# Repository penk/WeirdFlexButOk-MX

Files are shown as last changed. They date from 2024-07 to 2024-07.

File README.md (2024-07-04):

## WeirdFlexButOk - MX version

A hot-swappable, ergo monoblock split keyboard with tenting.

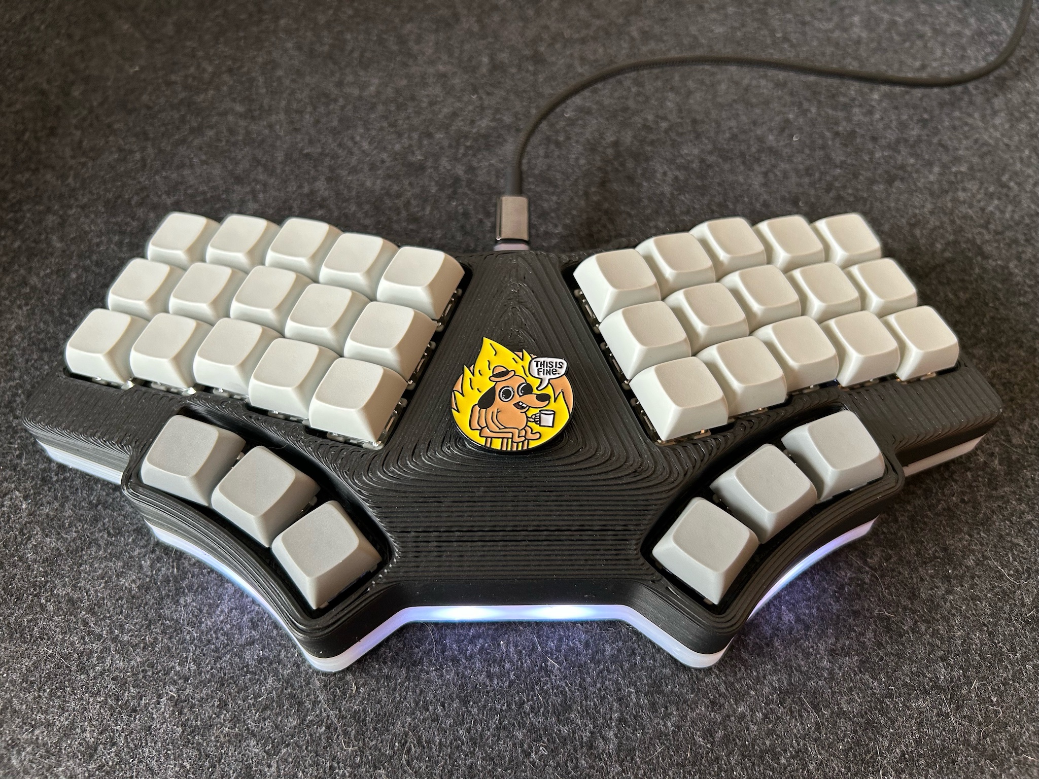
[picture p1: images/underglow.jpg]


Similar to the [Choc version](https://github.com/penk/WeirdFlexButOk), this keyboard features a `0.8mm` PCB with serpentine routing (kerf cuts) near the thumb clusters. These cuts allow the board to flex along the contour of the 3D printed case, forming a `20°` tilt and `10°` tent from a single PCB.

## Features

- Hot-swappable ergo monoblock split in MX spacing
- Built-in tenting (10°) and tilting (20°) from a single FR-4 PCB
- Breakable pinky columns, for 36 or 42-key layouts 
- Optional RGB underglow LEDs

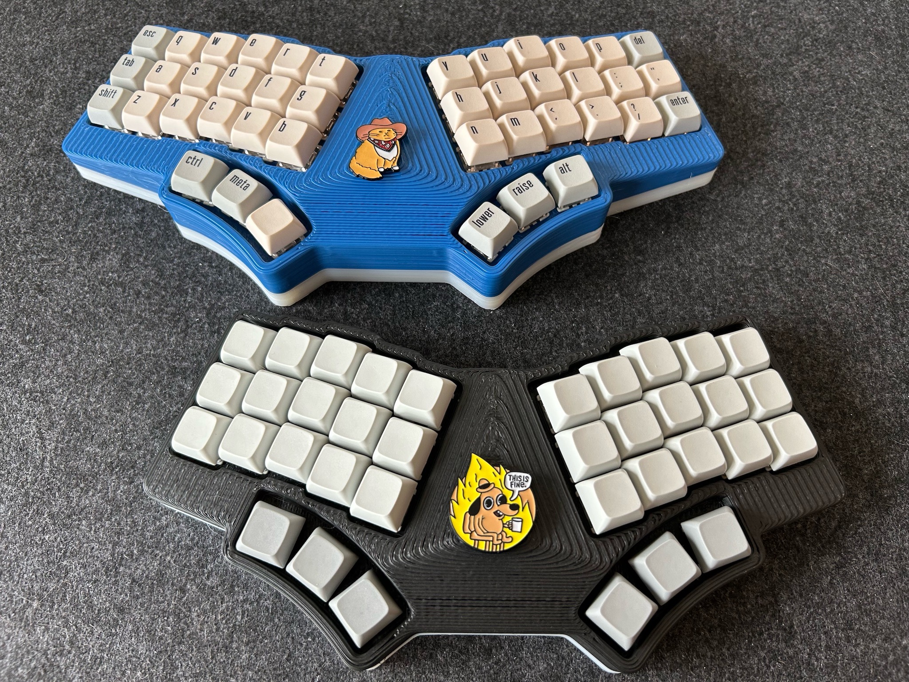
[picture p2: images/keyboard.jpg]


## Bill of Materials (BOM)

Quantity | Item
--- | ---
1 | Enamel pin badge (Optional)
1 | RP2040-Zero 
1 | WeirdFlexButOk-MX PCB
1 | WeirdFlexButOk-MX case & plate
36 (42) | MX Switches
36 (42) | MX Hot-swap sockets
36 (42) | 1N4148SOD-123 diodes
4 | WS2812B LEDs (Optional)
8 | M2x4 heat-set thread inserts
6 | M2x10 standoffs
14 | M2x6 screws

## Production Files

To place an order for the WeirdFlexButOk-MX PCB:

- Use the Gerber files available in the [production/](production/) folder.
- Optionally, the [BOM](production/BOM.csv) and [CPL](production/CPL.csv) files can be utilized with a PCBA service. All components, including the RP2040-Zero, are soldered to the bottom side of the board.

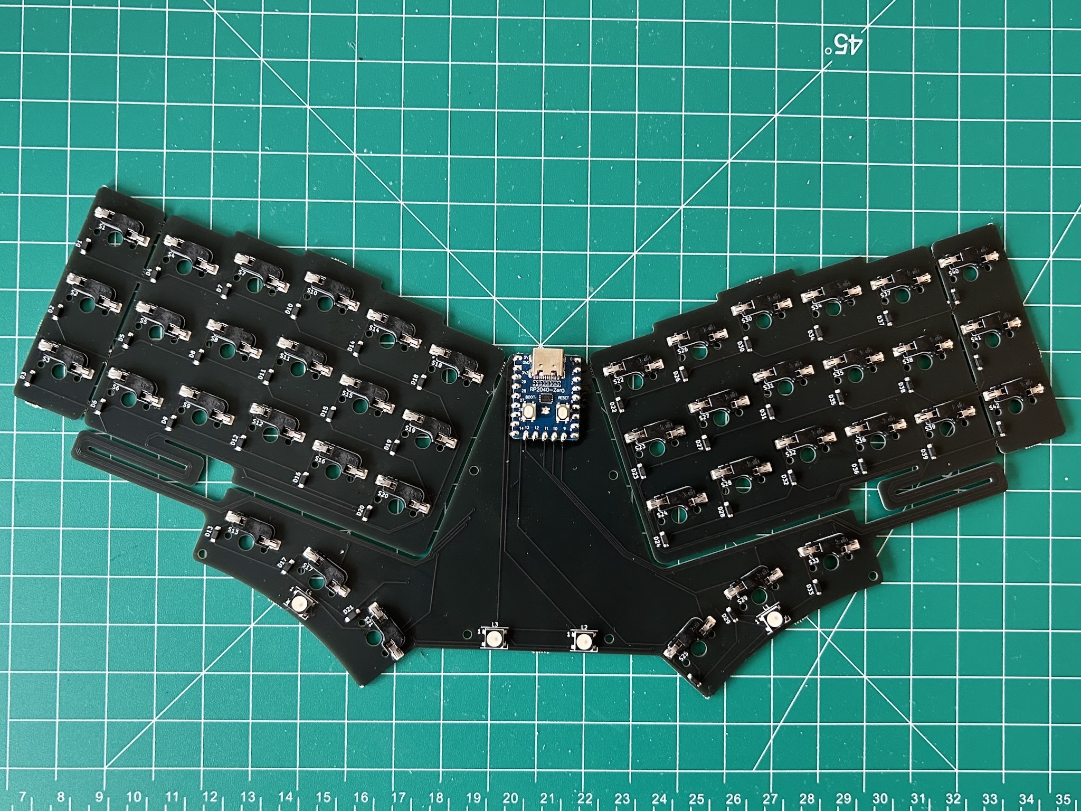
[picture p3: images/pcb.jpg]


Ensure you select the following specifications so the PCB can flex:

- Base Material: `FR4`
- PCB Thickness: `0.8mm`

The complete PCB design project is available in the [kicad/](kicad/) folder.

## 3D Printable Files

Print the case using the provided [STL files](case/) for the 36-key (3x5) or 42-key (3x6) layout respectively.

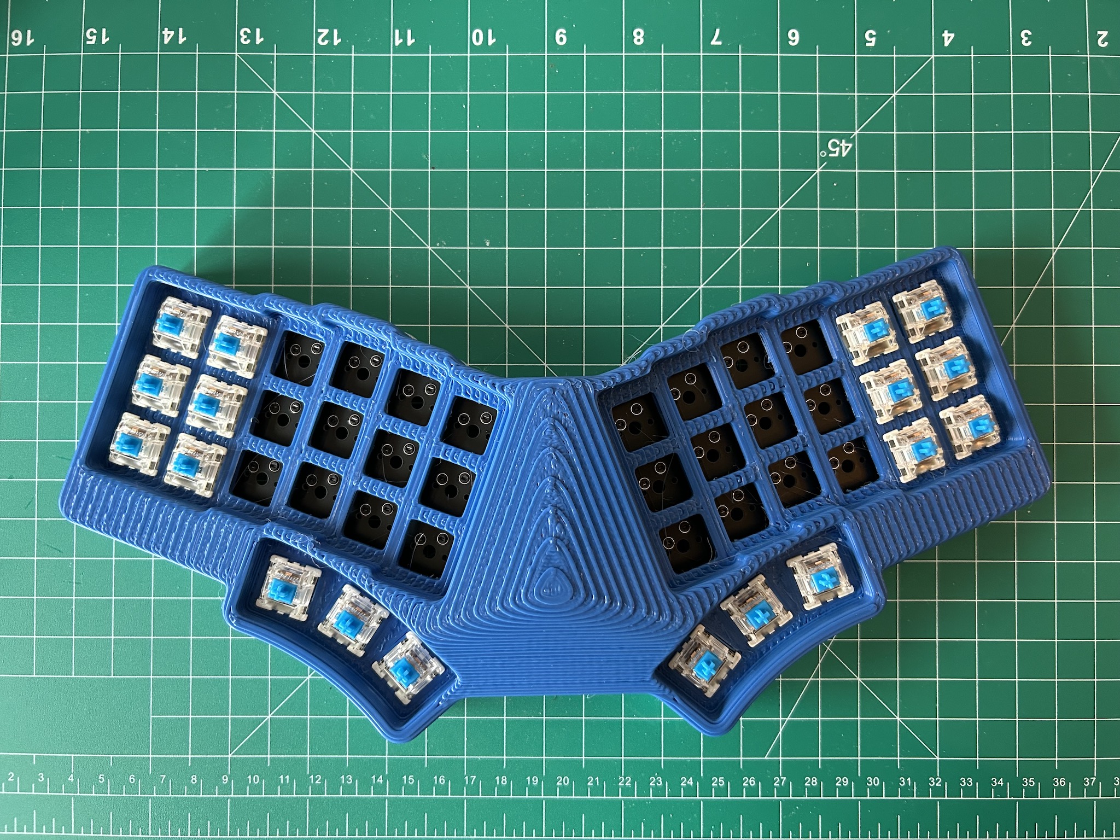
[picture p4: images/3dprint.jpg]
 

I like to start with translucent filament and add a mid-print filament change at around `10mm` height to let the LEDs shine through the bottom part. In Cura, this feature can be found under `Extensions` -> `Post Processing` -> `Modify G-Code` -> `Add a Script` -> `Filament Change`.

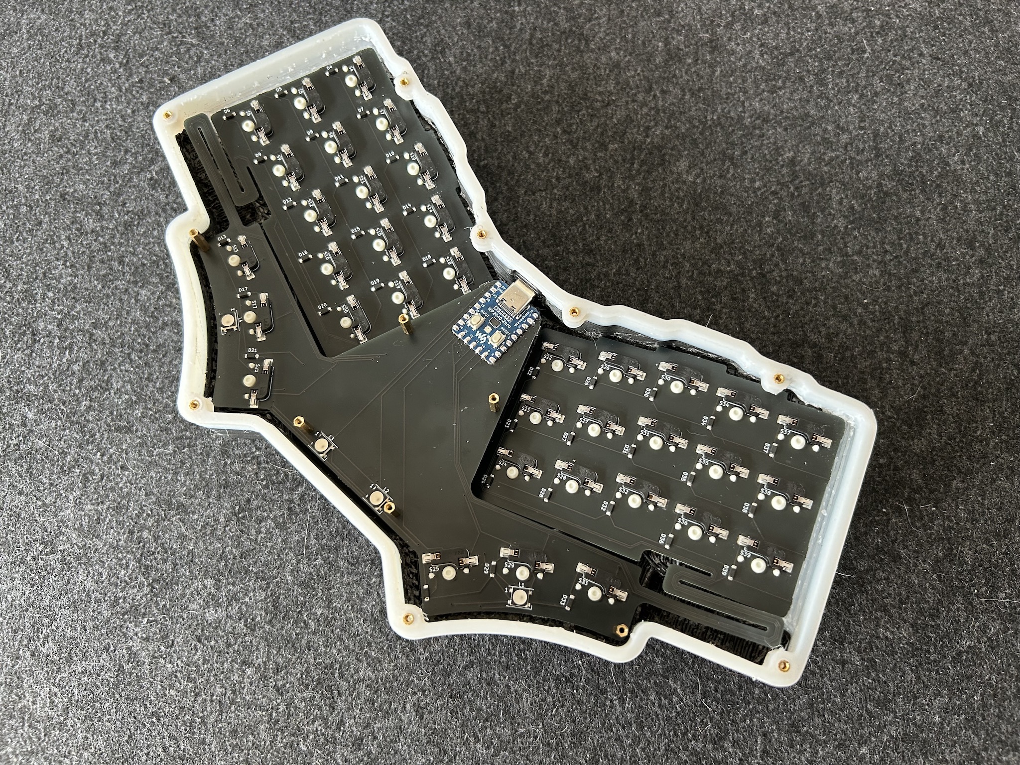
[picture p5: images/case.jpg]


Expect some amount of support material. Tolerances must be tuned for the switches (`14.2x14.2mm`) to fit properly.

I find the following parameters work best for my print:

- Top/Bottom Speed: 30 mm/s
- Support Structure: Tree
- Fan Speed Override: True
- Support Skin Fan Speed: 100%

## Firmware

Precompiled VIA-enabled firmware:

- Flash [penk_weirdflexbutok_mx_default.uf2](firmware/penk_weirdflexbutok_mx_default.uf2) to the RP2040-Zero.
- Load the [via.json](firmware/QMK/keyboards/weirdflexbutok_mx/via.json) file in `Design` tab for [VIA](https://usevia.app) configuration.

QMK source is available under [firmware/QMK/keyboards/weirdflexbutok_mx](firmware/QMK/keyboards/weirdflexbutok_mx).

## Copyright and License
Copyright (c) 2024 Penk Chen. All rights reserved.

All files are licensed under the MIT license. For more information, see the [LICENSE](LICENSE).

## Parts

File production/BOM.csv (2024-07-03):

Designator | Footprint | Quantity | Value | LCSC Part #
D1, D10, D11, D12, D13, D14, D15, D16, D17, D18, D19, D2, D20, D21, D22, D23, D24, D25, D26, D27, D28, D29, D3, D30, D31, D32, D33, D34, D35, D36, D37, D38, D39, D4, D40, D41, D42, D5, D6, D7, D8, D9 | Diode_SOD-123 | 42 | 1N4148SOD-123 | C2972760
L1, L2, L3, L4 | LED_WS2812B_PLCC4_5.0x5.0mm_P3.2mm | 4 | WS2812B | C2761795
S1, S10, S11, S12, S13, S14, S15, S16, S17, S18, S19, S2, S20, S21, S22, S23, S24, S25, S26, S27, S28, S29, S3, S30, S31, S32, S33, S34, S35, S36, S37, S38, S39, S4, S40, S41, S42, S5, S6, S7, S8, S9 | SW_MX_HS_1u | 42 | CPG151101S11-16 | C5156480

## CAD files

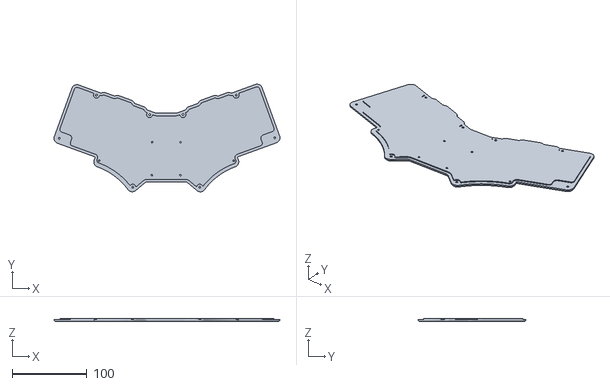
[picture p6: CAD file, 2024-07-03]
case/WFBO-MX-3x6-plate.stl
301.6 x 143.7 x 4.00

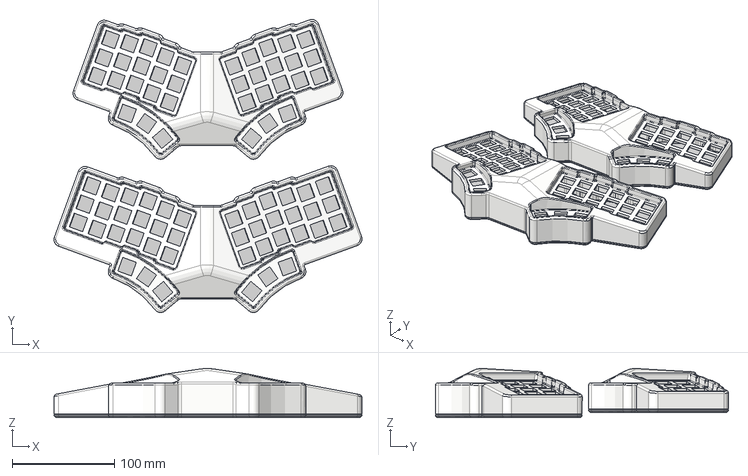
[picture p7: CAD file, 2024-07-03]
case/WFBO-MX-case.step
301.6 x 287.0 x 48.0 mm

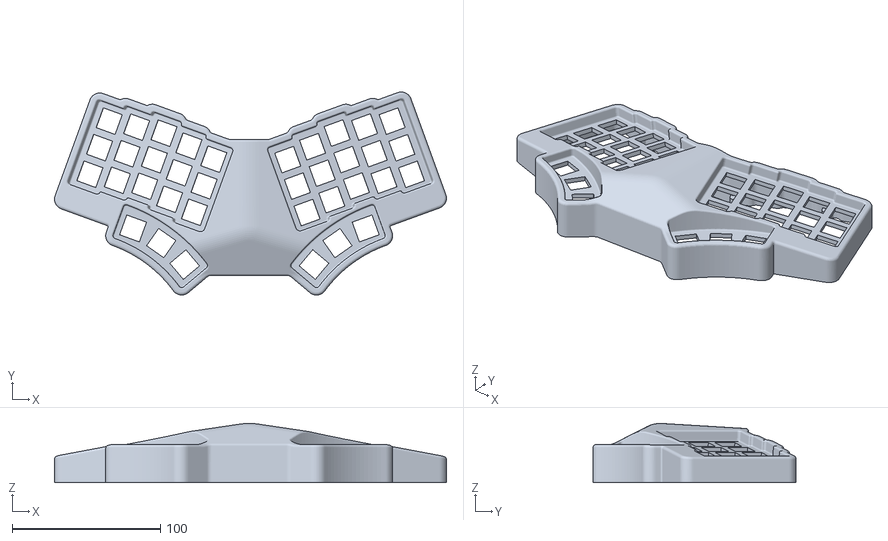
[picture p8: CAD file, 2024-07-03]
case/WFBO-MX-3x5-case.stl
264.4 x 136.9 x 39.9

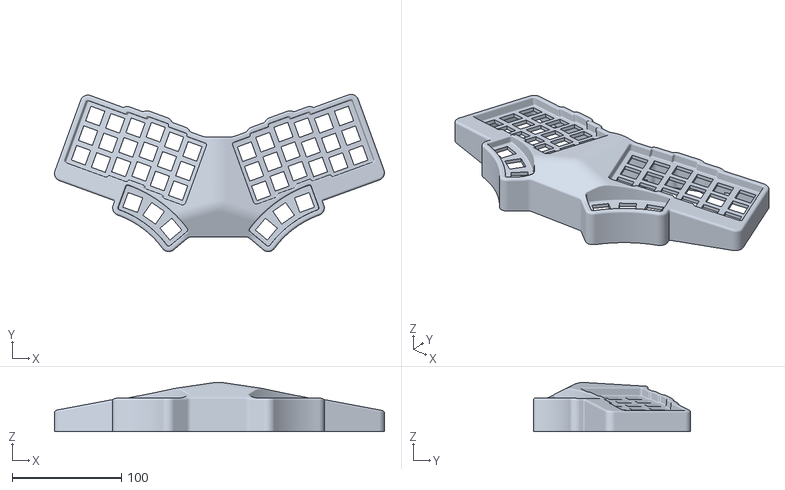
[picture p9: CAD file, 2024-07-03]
case/WFBO-MX-3x6-case.stl
301.6 x 143.7 x 44.9

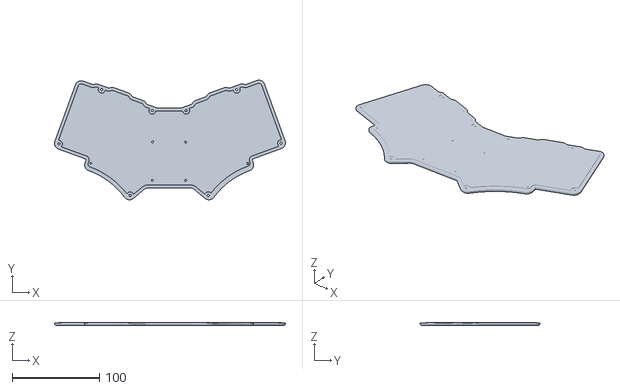
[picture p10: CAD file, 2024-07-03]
case/WFBO-MX-3x5-plate.stl
264.4 x 136.9 x 4.00

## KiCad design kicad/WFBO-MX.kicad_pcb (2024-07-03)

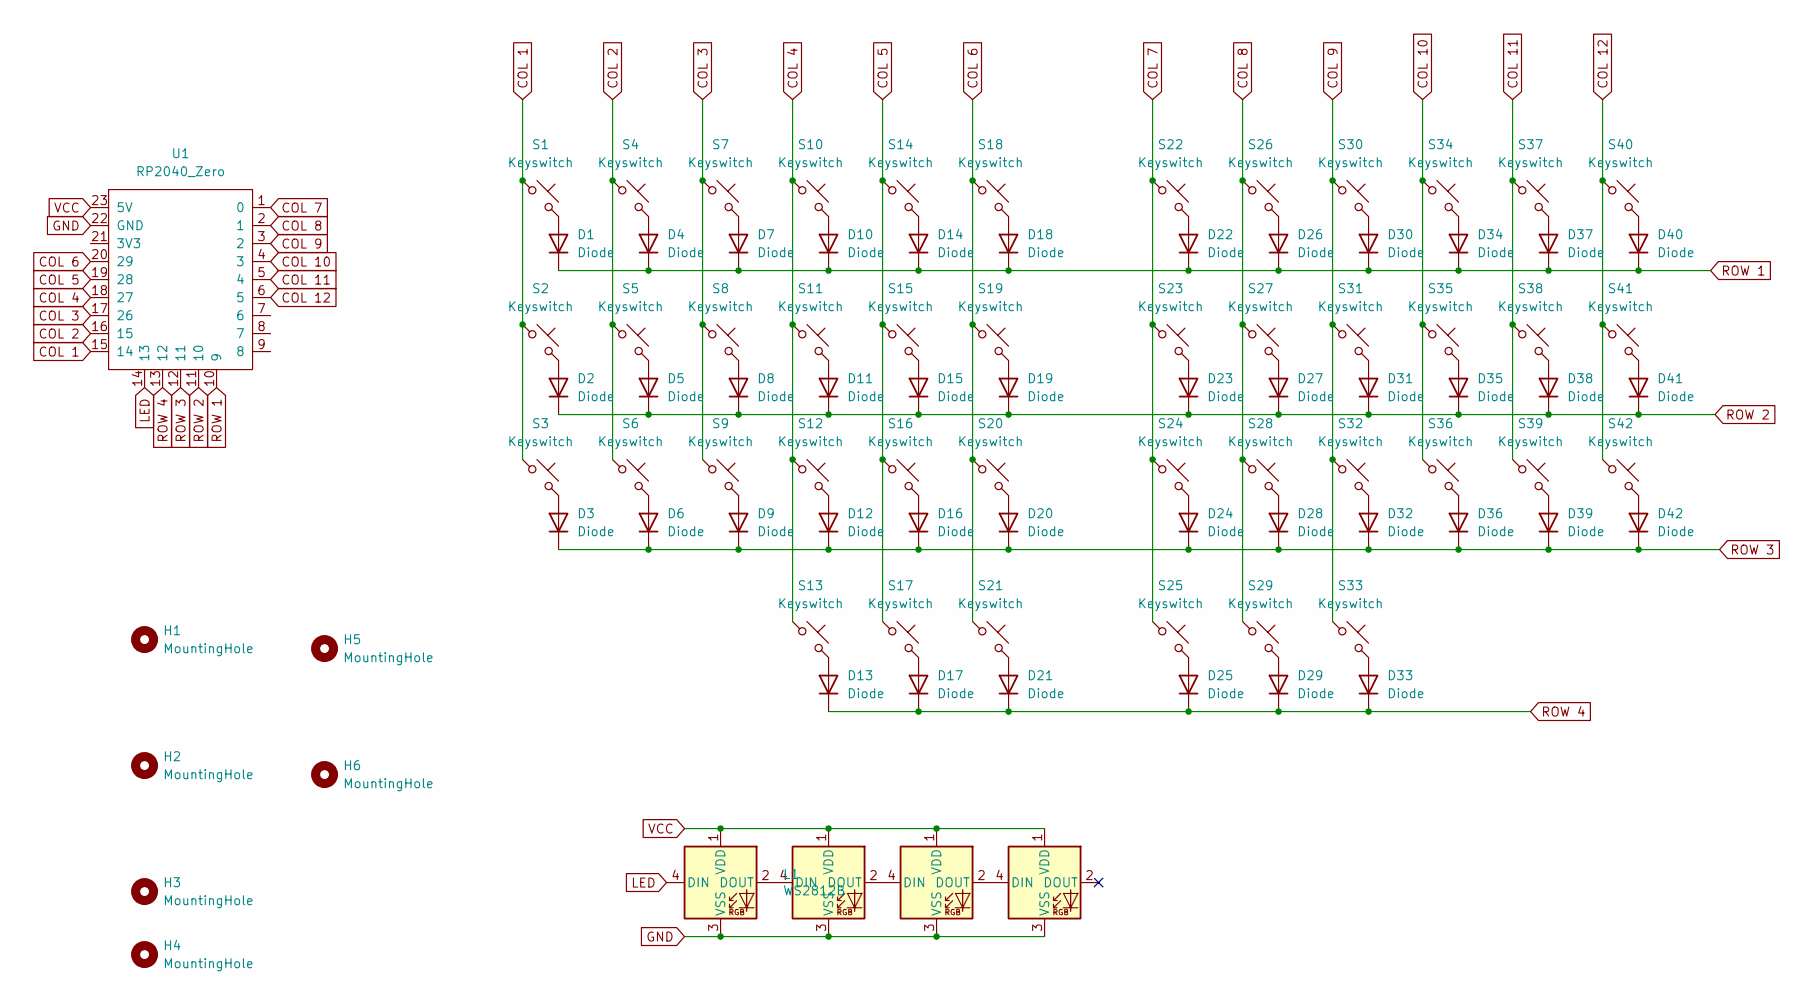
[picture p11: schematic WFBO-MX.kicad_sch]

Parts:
D1, D2, D3, D4, D5, D6, D7, D8, D9, D10, D11, D12, D13, D14, D15, D16, D17, D18, D19, D20, D21, D22, D23, D24, D25, D26, D27, D28, D29, D30, D31, D32, D33, D34, D35, D36, D37, D38, D39, D40, D41, D42: Diode; Diode_SOD-123
H1, H2, H3, H4, H5, H6: MountingHole; MountingHole_2.2mm_M2
L1, L2, L3, L4: WS2812B; LED_WS2812B_PLCC4_5.0x5.0mm_P3.2mm
S1, S2, S3, S4, S5, S6, S7, S8, S9, S10, S11, S12, S13, S14, S15, S16, S17, S18, S19, S20, S21, S22, S23, S24, S25, S26, S27, S28, S29, S30, S31, S32, S33, S34, S35, S36, S37, S38, S39, S40, S41, S42: Keyswitch; SW_MX_HS_1u
U1: RP2040_Zero

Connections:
COL 1: S1.1, S2.1, S3.1, U1.15 (14)
COL 2: S4.1, S5.1, S6.1, U1.16 (15)
COL 3: S7.1, S8.1, S9.1, U1.17 (26)
COL 4: S10.1, S11.1, S12.1, S13.1, U1.18 (27)
COL 5: S14.1, S15.1, S16.1, S17.1, U1.19 (28)
COL 6: S18.1, S19.1, S20.1, S21.1, U1.20 (29)
COL 7: S22.1, S23.1, S24.1, S25.1, U1.1 (0)
COL 8: S26.1, S27.1, S28.1, S29.1, U1.2 (1)
COL 9: S30.1, S31.1, S32.1, S33.1, U1.3 (2)
COL 10: S34.1, S35.1, S36.1, U1.4 (3)
COL 11: S37.1, S38.1, S39.1, U1.5 (4)
COL 12: S40.1, S41.1, S42.1, U1.6 (5)
GND: L1.3 (VSS), L2.3 (VSS), L3.3 (VSS), L4.3 (VSS), U1.22 (GND)
LED: L1.4 (DIN), U1.14 (13)
unnamed: D1.2 (A), S1.2
unnamed: D2.2 (A), S2.2
unnamed: D3.2 (A), S3.2
unnamed: D4.2 (A), S4.2
unnamed: D5.2 (A), S5.2
unnamed: D6.2 (A), S6.2
unnamed: D7.2 (A), S7.2
unnamed: D8.2 (A), S8.2
unnamed: D9.2 (A), S9.2
unnamed: D10.2 (A), S10.2
unnamed: D11.2 (A), S11.2
unnamed: D12.2 (A), S12.2
unnamed: D13.2 (A), S13.2
unnamed: D14.2 (A), S14.2
unnamed: D15.2 (A), S15.2
unnamed: D16.2 (A), S16.2
unnamed: D17.2 (A), S17.2
unnamed: D18.2 (A), S18.2
unnamed: D19.2 (A), S19.2
unnamed: D20.2 (A), S20.2
unnamed: D21.2 (A), S21.2
unnamed: D22.2 (A), S22.2
unnamed: D23.2 (A), S23.2
unnamed: D24.2 (A), S24.2
unnamed: D25.2 (A), S25.2
unnamed: D26.2 (A), S26.2
unnamed: D27.2 (A), S27.2
unnamed: D28.2 (A), S28.2
unnamed: D29.2 (A), S29.2
unnamed: D30.2 (A), S30.2
unnamed: D31.2 (A), S31.2
unnamed: D32.2 (A), S32.2
unnamed: D33.2 (A), S33.2
unnamed: D34.2 (A), S34.2
unnamed: D35.2 (A), S35.2
unnamed: D36.2 (A), S36.2
unnamed: D37.2 (A), S37.2
unnamed: D38.2 (A), S38.2
unnamed: D39.2 (A), S39.2
unnamed: D40.2 (A), S40.2
unnamed: D41.2 (A), S41.2
unnamed: D42.2 (A), S42.2
unnamed: L1.2 (DOUT), L2.4 (DIN)
unnamed: L2.2 (DOUT), L3.4 (DIN)
unnamed: L3.2 (DOUT), L4.4 (DIN)
ROW 1: D1.1 (K), D4.1 (K), D7.1 (K), D10.1 (K), D14.1 (K), D18.1 (K), D22.1 (K), D26.1 (K), D30.1 (K), D34.1 (K), D37.1 (K), D40.1 (K), U1.10 (9)
ROW 2: D2.1 (K), D5.1 (K), D8.1 (K), D11.1 (K), D15.1 (K), D19.1 (K), D23.1 (K), D27.1 (K), D31.1 (K), D35.1 (K), D38.1 (K), D41.1 (K), U1.11 (10)
ROW 3: D3.1 (K), D6.1 (K), D9.1 (K), D12.1 (K), D16.1 (K), D20.1 (K), D24.1 (K), D28.1 (K), D32.1 (K), D36.1 (K), D39.1 (K), D42.1 (K), U1.12 (11)
ROW 4: D13.1 (K), D17.1 (K), D21.1 (K), D25.1 (K), D29.1 (K), D33.1 (K), U1.13 (12)
VCC: L1.1 (VDD), L2.1 (VDD), L3.1 (VDD), L4.1 (VDD), U1.23 (5V)

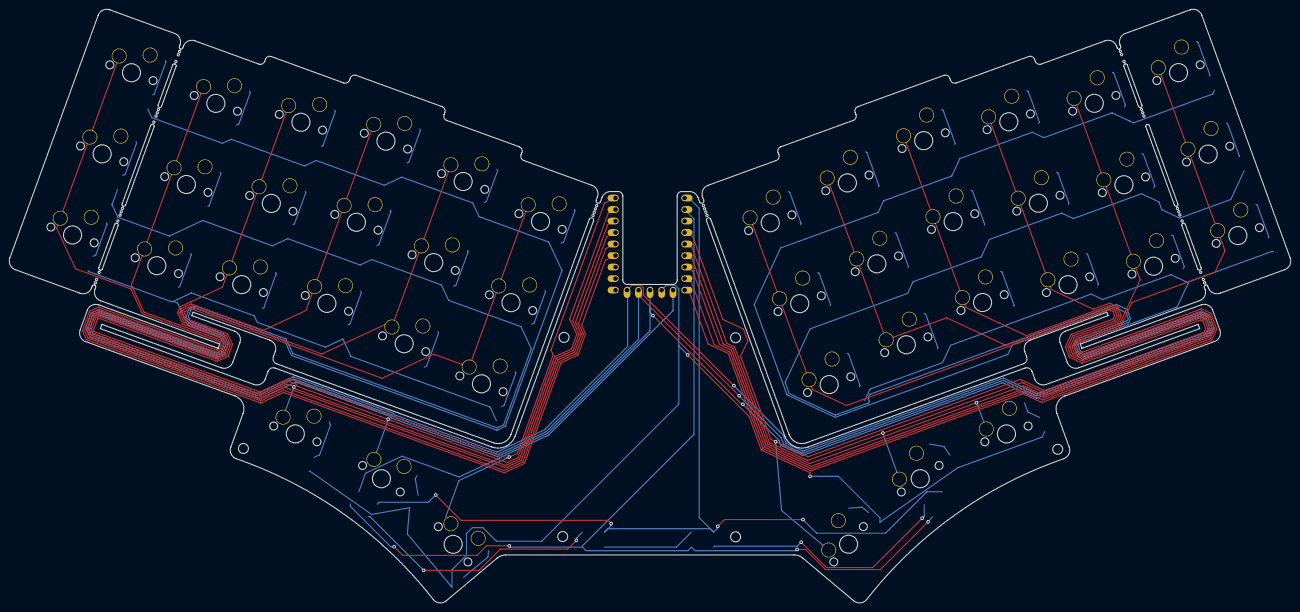
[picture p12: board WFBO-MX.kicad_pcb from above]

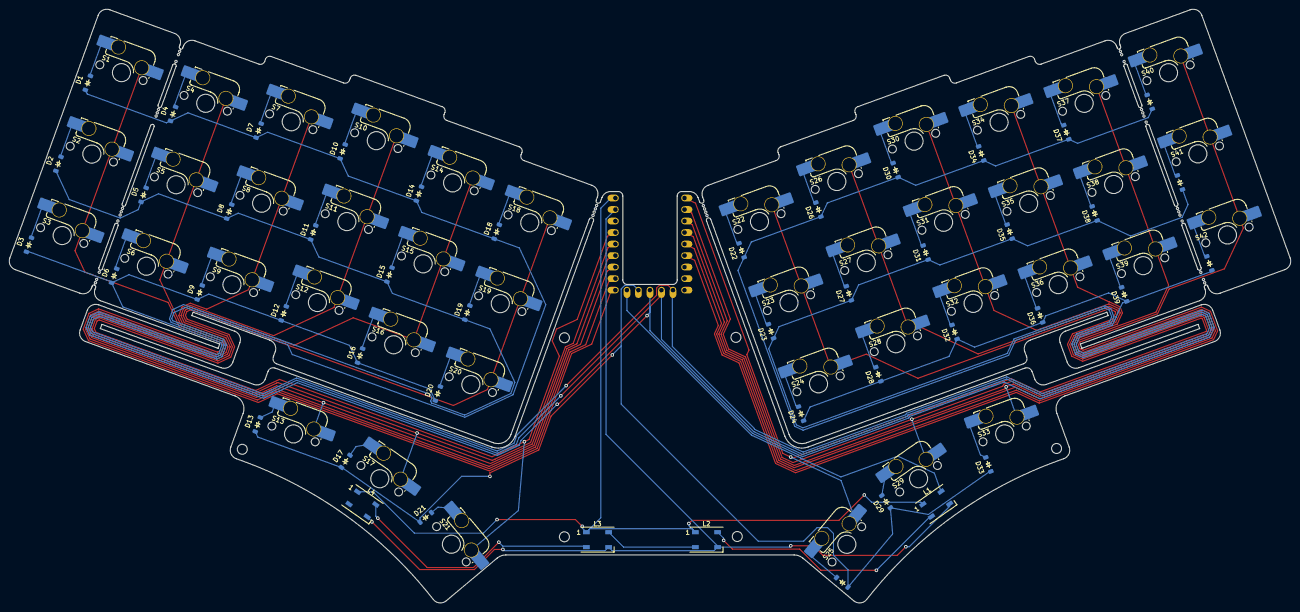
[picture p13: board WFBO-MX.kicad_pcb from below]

Board: 2 copper layers, 282.7 x 131.0 mm, 95 parts (89 on the bottom side), 64 nets.

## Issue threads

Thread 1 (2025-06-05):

Switch hard to install

ufo22940268, 2025-06-05:
Thanks for your design, really good.

But after i print the case and plate and then try to install the switch to pcb under the case, i found it really hard to install. Because the switch hard to align with the pcb under the case. And seems like the pcb can't attach to pcb because there is not enough room in the left and right. Do you have the latest case design model? thanks a lot

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

penk, 2025-06-05:
@ufo22940268 Thanks for the comment! Since the whole assembly is movable, I recommend starting with the six thumb cluster keys. Once you have the PCB aligned and partially pinned to the printed case, begin installing switches from the corners and work your way toward the center.

Closed 2025-06-05.
